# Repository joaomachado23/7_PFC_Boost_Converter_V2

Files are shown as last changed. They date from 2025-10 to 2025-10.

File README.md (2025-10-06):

# 7_PFC_Boost_Converter_V2

O objetivo deste trabalho foi o design, simulação, conceção e teste de um protótipo funcional de conversor de potência, a apresentar no final do semestre. Todos os grupos tiveram de desenvolver um Conversor CA-CC do tipo Boost PFC, respeitando requisitos de tensão e corrente definidos.

O conversor era constituído por um estágio CA-CC, com transformador abaixador e ponte retificadora de díodos (retificação síncrona), seguido de um estágio CC-CC na topologia Boost com carga resistiva. O estágio Boost operava com um método de controlo do tipo PFC (Power Factor Correction), cujo objetivo é corrigir o fator de potência e reduzir a potência reativa no sistema.

O nosso grupo optou por implementar um protótipo praticamente integrado em PCB, que inclui:

1. Andar de potência (com PGND) — engloba todos os componentes dos estágios CA-CC e CC-CC, incluindo sensores de tensão e de corrente (ambos de efeito Hall), excetuando o transformador, que ficou fora da PCB;

2. Andar de controlo (com SGND) — inclui:

  - Circuitos de alimentação auxiliares: num conector liga-se uma fonte de bancada que fornece ±15 V; essa tensão é depois convertida para 5 V e 3,3 V por reguladores (um conversor buck síncrono e um LDO).
  - Circuito de condicionamento de sinal: um IC com dois amplificadores operacionais em configuração diferencial (sensor de corrente) e em seguidor de tensão (sensor de tensão), filtros analógicos passa-baixo de primeira ordem e proteção para o ADC.
  - Microcontrolador e interface de comunicação série (UART ↔ USB): um STM32G474RET6 incorporado na placa, com os circuitos de alimentação, reset e programação dimensionados conforme a aplicação e o fabricante.

Todo o design foi concebido e verificado em ambiente de simulação (PSIM), tanto ao nível do hardware de potência como da teoria de controlo aplicada. Importa destacar que, nesta iteração, o controlo era linear: o sinal da gate do IGBT apresentava frequência fixa e era gerado por comparação entre uma portadora triangular (frequência e amplitude fixas) e uma moduladora, que corresponde à saída de um controlador PI. Essa moduladora era limitada posteriormente entre 0 e 70 (i.e., duty-cycle fisicamente limitado entre 0% e 70%).

O conversor era controlado por corrente, com referência de corrente do lado da rede (4 Arms). A referência era comparada com o valor instantâneo da corrente na bobina; a diferença constituía a entrada do controlador PI.

Os resultados obtidos foram bastante satisfatórios e promissores, sobretudo tendo em conta que a tecnologia ficou praticamente toda embebida na PCB, incluindo o microcontrolador. Para tornar o conversor independente de fontes de bancada externas, o grupo considerou ser adequado, numa versão futura, ligar um módulo conversor CC-CC isolado à saída da ponte retificadora, tomando os cuidados necessários para não comprometer o objetivo do controlo PFC.

Conteúdos disponíveis neste repositório:

- PDF com toda a documentação do projeto (apresentação): estado da arte, design, simulação, conceção, testes e resultados.

- Ficheiro rar com fotos e vídeos do protótipo.

- Pasta com prints de resultados dos testes ao conversor.

- Ficheiro PSIM (.psimsch) com a simulação do conversor.
  
- Pasta com o projeto da PCB feito em Altium.

Este trabalho foi fundamental para explorar o desafio de integrar toda a tecnologia numa PCB e para consolidar conhecimentos em eletrónica de potência, com foco no hardware de potência, condicionamento de sinal e firmware de controlo. Foi um projeto exigente, dadas todas as condicionantes a ter em atenção e não esquecendo a função principal do conversor, mas foi concluído com sucesso.

Um grande obrigado aos colegas que me acompanharam nesta jornada: Diego Brandão, Francisco Costa, João Santos e Rui Pedroso.

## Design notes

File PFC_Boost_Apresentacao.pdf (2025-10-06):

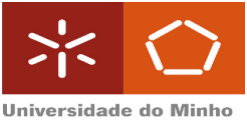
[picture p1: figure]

Escola de Engenharia
Departamento de Electrónica Industrial

## Eletrónica de Potência e Energias

## Conversor Unidirecional CA-CC Boost PFC

Dep. de Electrónica Industrial

## Constituição do grupo

◼ Diego Soares Brandão

◼ pg53769@alunos.uminho.pt

◼ Francisco Faria Costa

◼ pg53819@alunos.uminho.pt

◼ João Pedro Machado da Silva

◼ pg53942@alunos.uminho.pt

◼ João Pedro Medeiros Santos

◼ a94596@alunos.uminho.pt

◼ Rui Pedro Fernandes Pedroso

◼ | pg54212@alunos.uminho.pt
06/10/2025 | Universidade do Minho, MEEIC - EPE | 2

Dep. de Electrónica Industrial

## Índice

◼ Estado da arte;

◼ Diagrama de blocos;

◼ Etapas do trabalho desenvolvido;

◼ Simulação;

◼ Hardware;

◼ Testes e Resultados experimentais;
◼ Conclusão;

◼ Bibliografia;

Dep. de Electrónica Industrial

## Estado da Arte

◼ O algoritmo Power Factor Correction (Correção do Fator de Potência – PFC) surge como uma ferramenta para otimizar a utilização da energia;

◼ É cada vez mais necessário reduzir as perdas, devido ao aumento do consumo de energia;

◼ A otimização da energia é feita não só através da correção do fator de potência, mas também através do consumo de corrente sinusoidal;

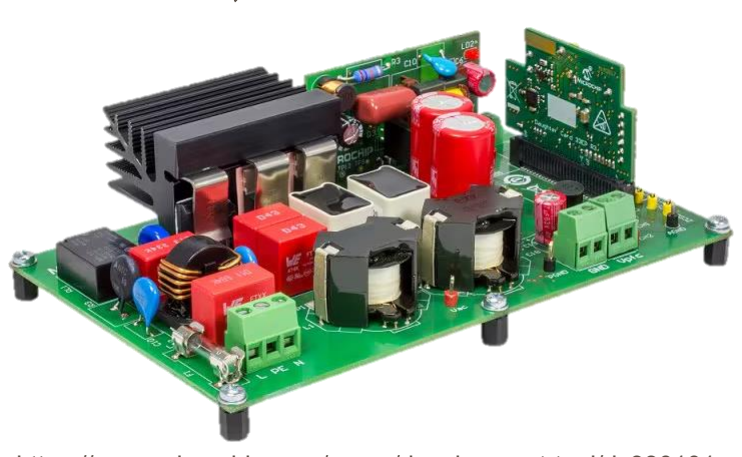
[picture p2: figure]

https://www.microchip.com/en-us/development-tool/dv330101

## Diagrama de blocos

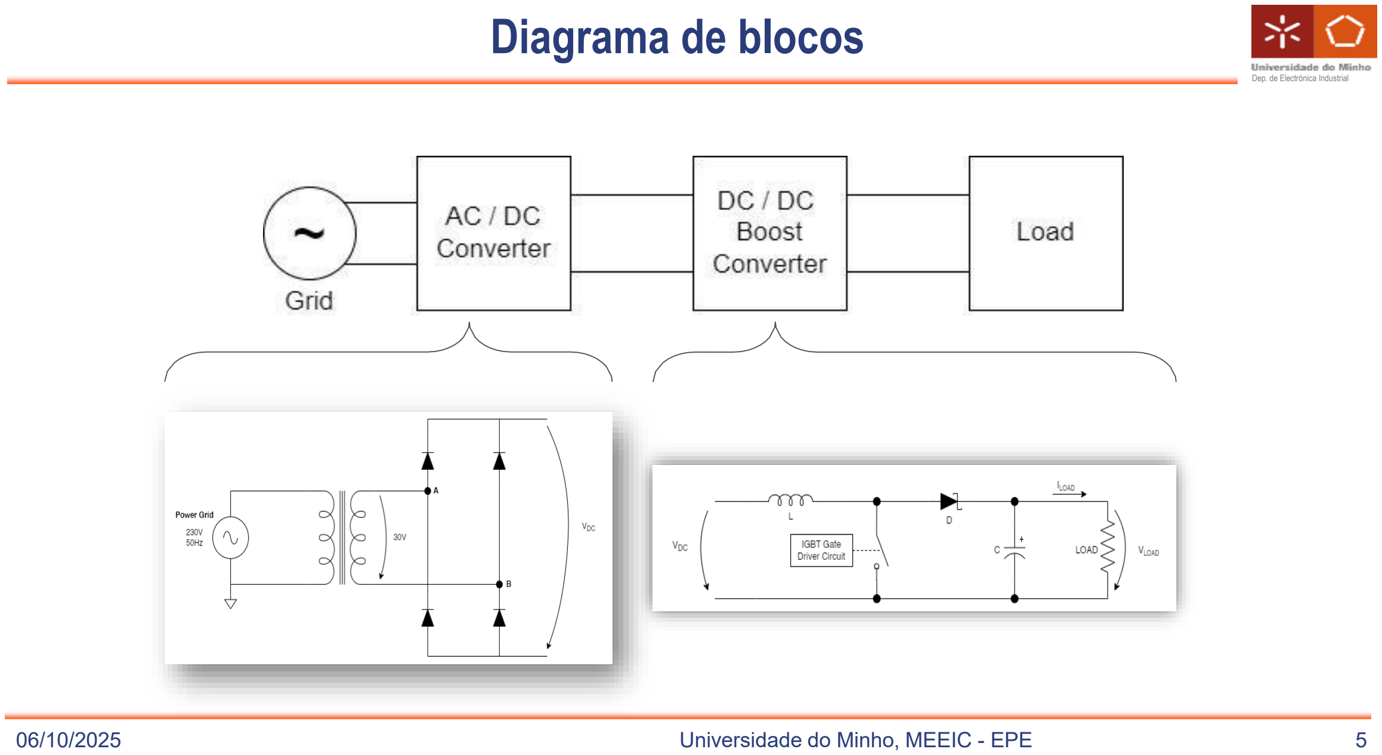
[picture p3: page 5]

Dep. de Electrónica Industrial

## Circuito simulado com valores reais

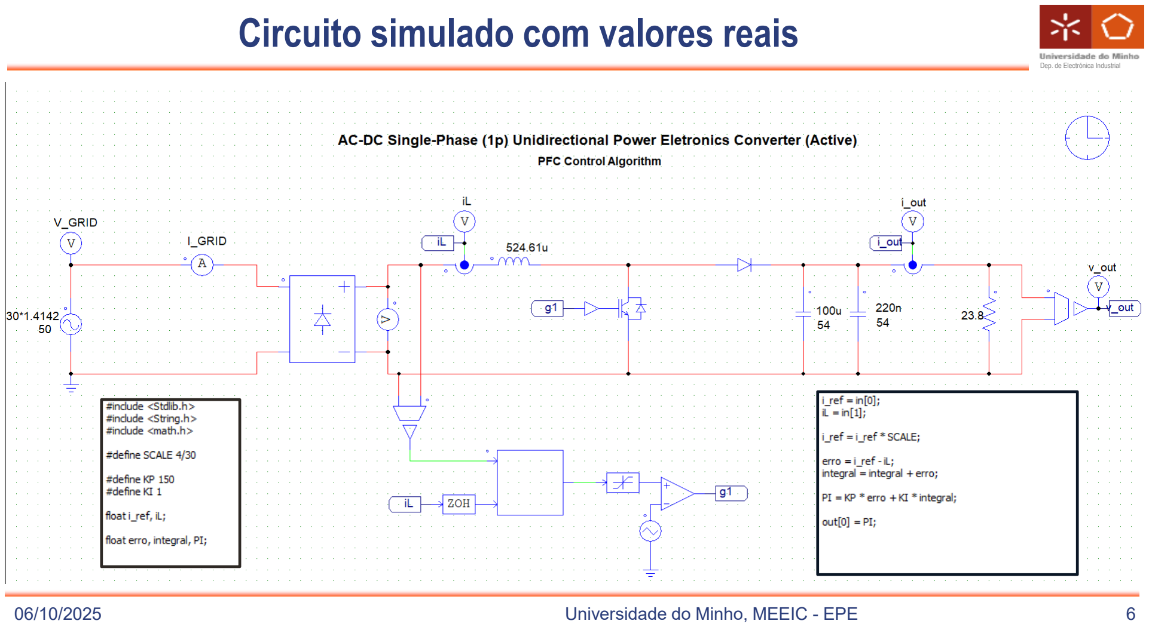
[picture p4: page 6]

Dep. de Electrónica Industrial

## Resultados da simulação: (trocar a print)

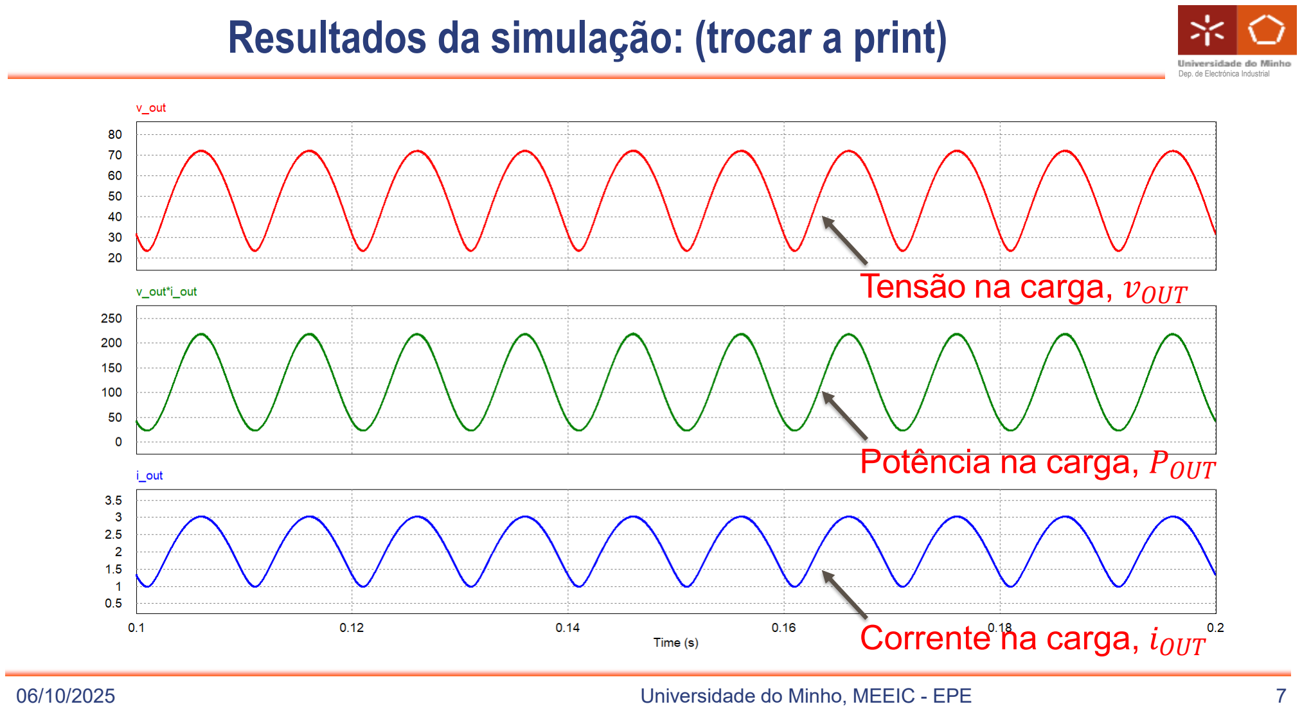
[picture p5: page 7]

Dep. de Electrónica Industrial

Tensão na carga, vOUT

Potência na carga, POUT

Corrente na carga, iOUT

## Resultados da simulação (trocar as prints)

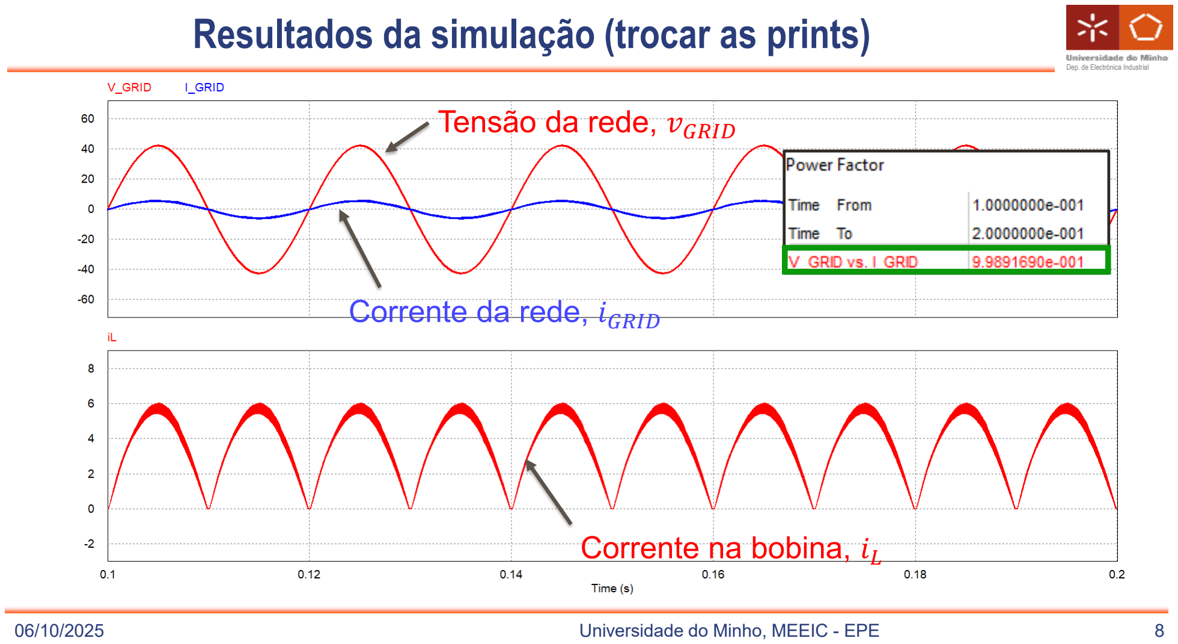
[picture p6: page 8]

Dep. de Electrónica Industrial
Tensão da rede, vGRID

Corrente da rede, iGRID

Corrente na bobina, iL

Dep. de Electrónica Industrial

## Controlo

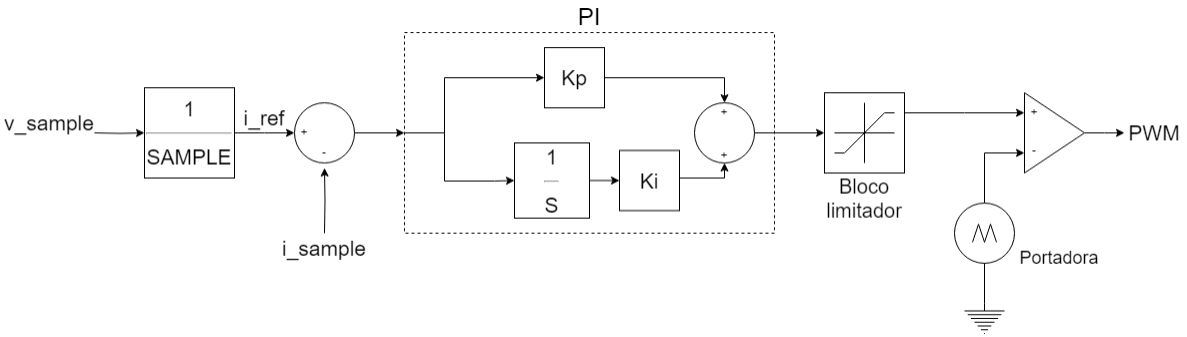
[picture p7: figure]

06/10/2025 | Universidade do Minho, MEEIC - QEFAP | 9

◼ Teoria de controlo utilizada – PI estacionário com modulação PWM (controlo linear)

Dep. de Electrónica Industrial

## Hardware

◼ Microcontrolador utilizado: SMT32G474RET6

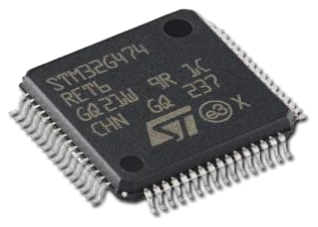
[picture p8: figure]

◼ Clock até 170MHz;

◼ 5 x ADCs de 12Bits, 4MSps;

◼ 17 timers, 6 deles de 16Bit;

◼ Mathematical Hardware Acelerator;

◼ FPU;

06/10/2025 | Universidade do Minho, MEEIC - QEFAP | 10

https://pt.aliexpress.com/i/1005005631876638.html

Dep. de Electrónica Industrial

## Hardware

◼ Gate driver: ADuM 3123

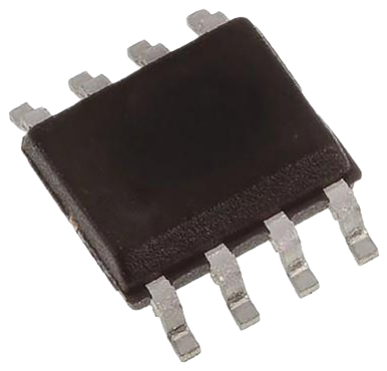
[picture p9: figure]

◼ Bandwitdh de 1MHz;

◼ 3000V rms isolation;

◼ 64ns maximum propagation delay;

06/10/2025 | Universidade do Minho, MEEIC - QEFAP | 11

https://sg.rs-online.com/web/p/digital-isolator-ics/9053567

Dep. de Electrónica Industrial

## Hardware

◼ Sensor de tensão: CYHVS5-25A

◼ Tensão máxima de entrada: 2000V;

◼ Tensão de isolamento 2.5kV;

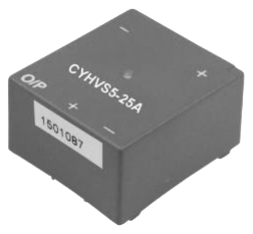
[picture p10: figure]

06/10/2025 | Universidade do Minho, MEEIC - QEFAP | 12

◼ Sensor de tensão: LTSR15-np

◼ Corrente máxima de entrada: 15A;

◼ Sensibilidade: 41.6mV/A;

https://shorturl.at/5qOIk

## Hardware - PCB

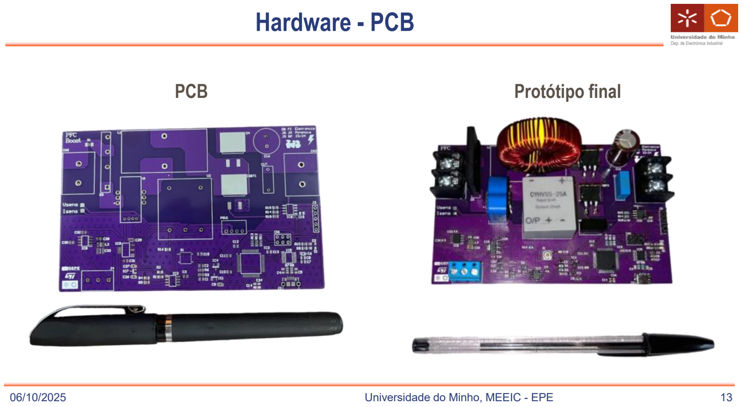
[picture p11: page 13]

Dep. de Electrónica Industrial

PCB

Protótipo final

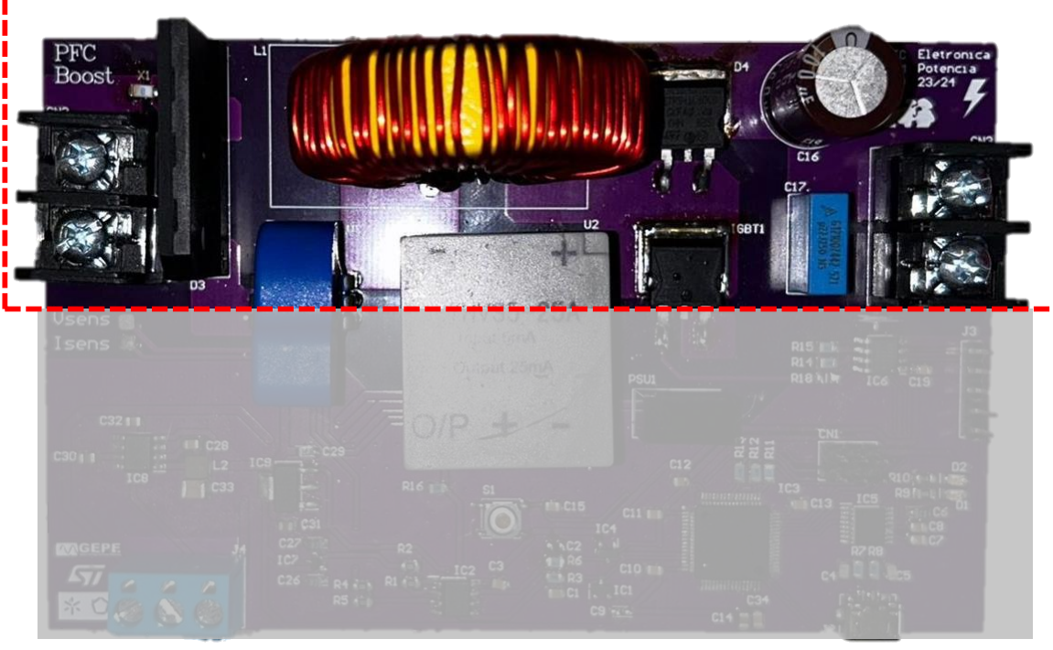
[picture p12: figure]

Dep. de Electrónica Industrial

## Hardware - PCB

Circuito de
potência

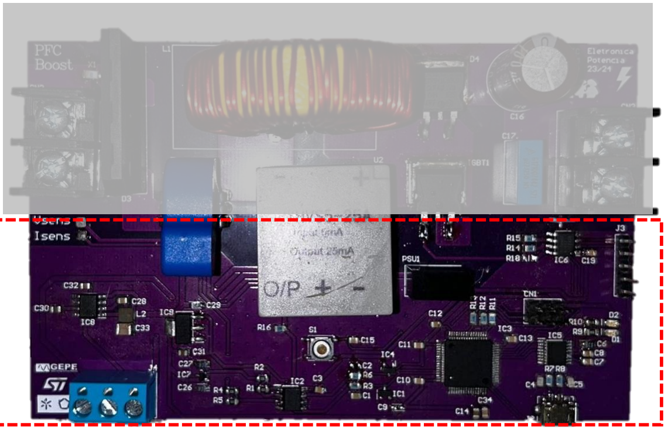
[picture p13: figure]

Dep. de Electrónica Industrial

## Hardware - PCB

Circuito de
controlo

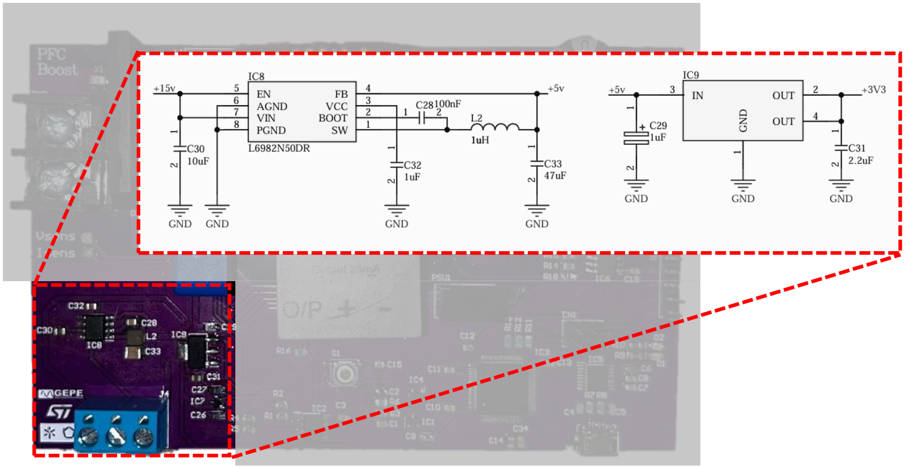
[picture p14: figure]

Dep. de Electrónica Industrial

## Hardware - PCB

Circuito de
alimentações

## Hardware - PCB

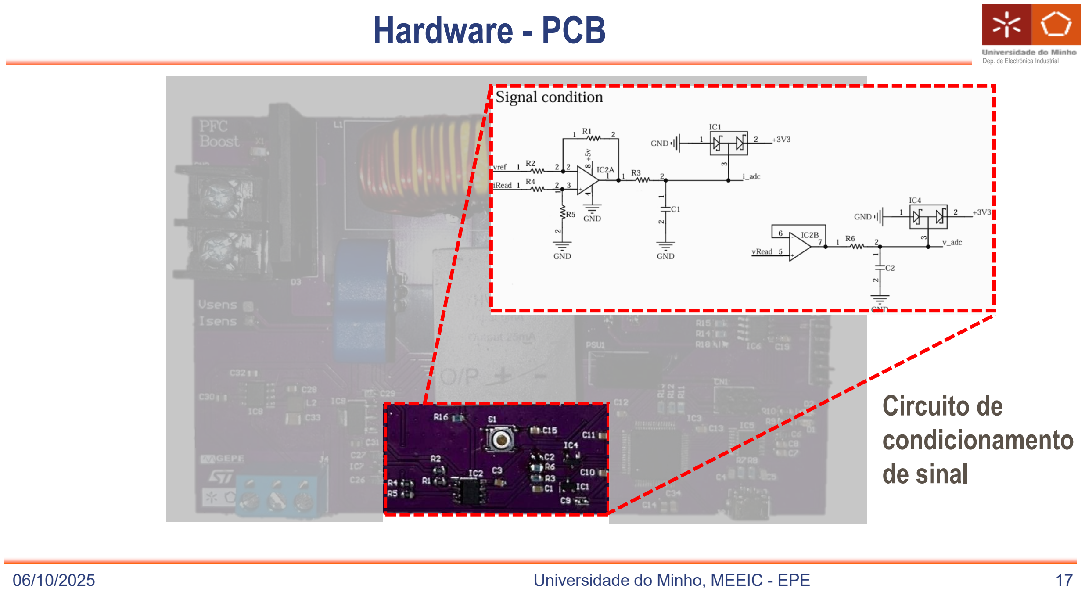
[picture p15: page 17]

Dep. de Electrónica Industrial

Circuito de
condicionamento
de sinal

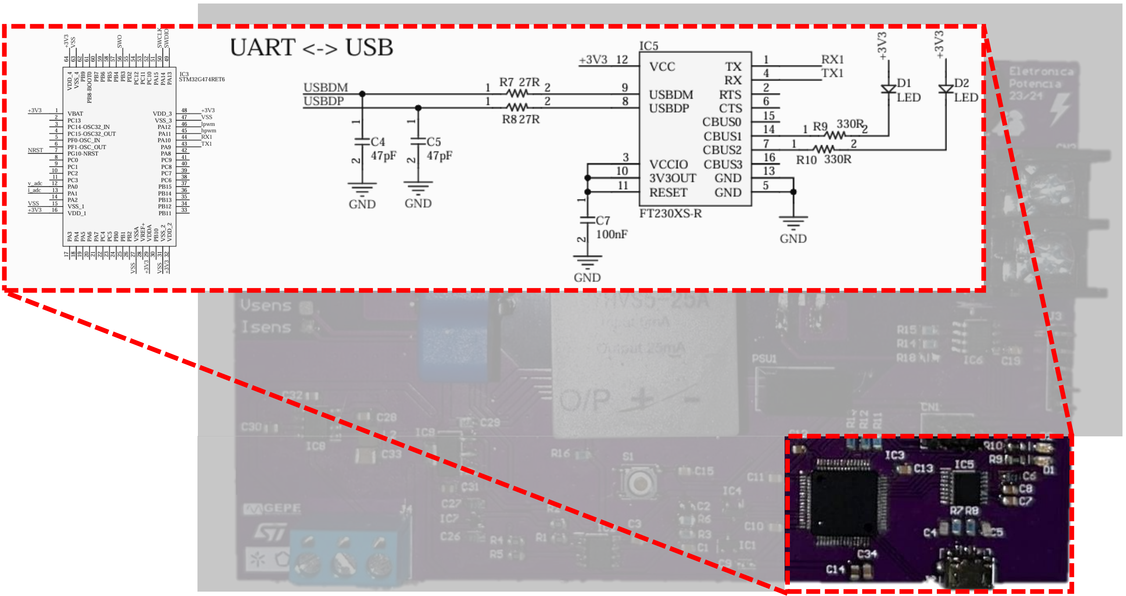
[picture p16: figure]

Dep. de Electrónica Industrial

## Hardware - PCB

Microcontrolador
e circuito para
comunicação por
porta série

## Bancada de testes

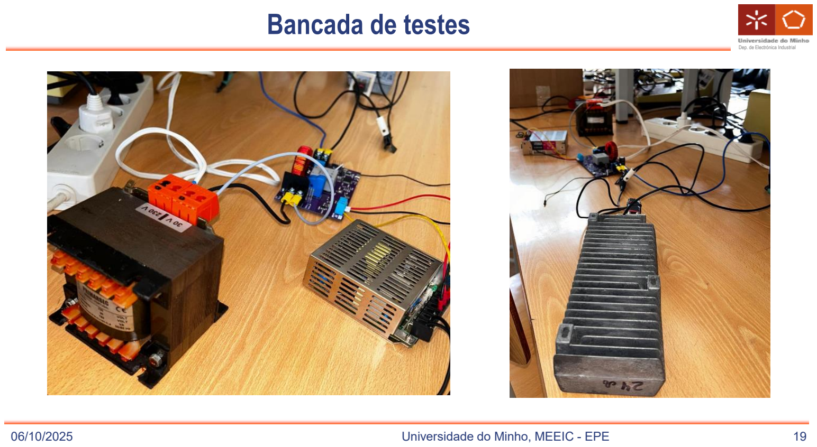
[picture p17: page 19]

Dep. de Electrónica Industrial

Dep. de Electrónica Industrial

## Resultados experimentais - Testes pwm

PWM do circuito de controlo

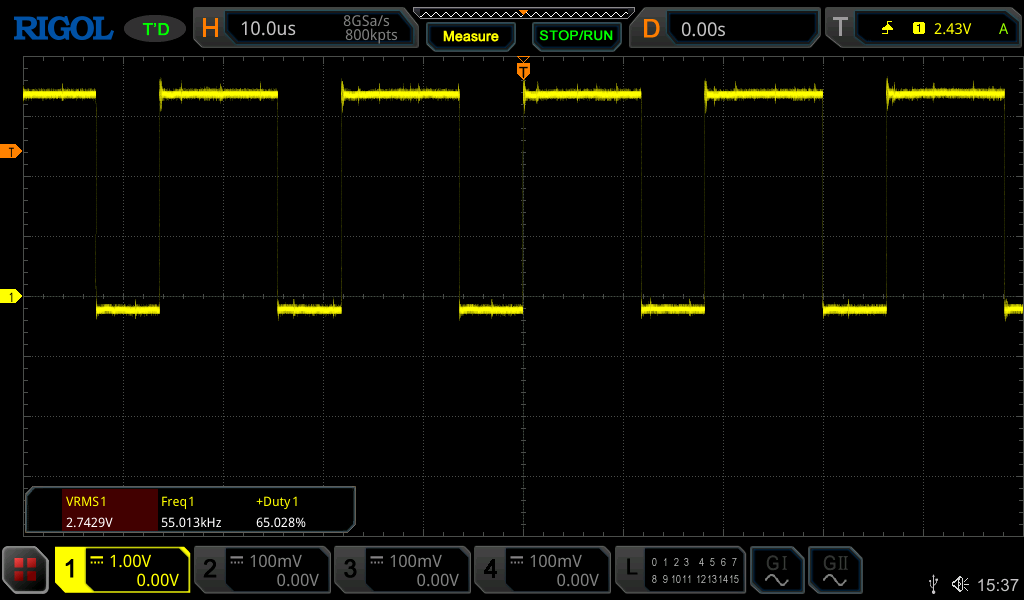
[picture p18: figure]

Duty = 65%

Dep. de Electrónica Industrial

## Resultados experimentais – Testes pwm

PWM no circuito de potência

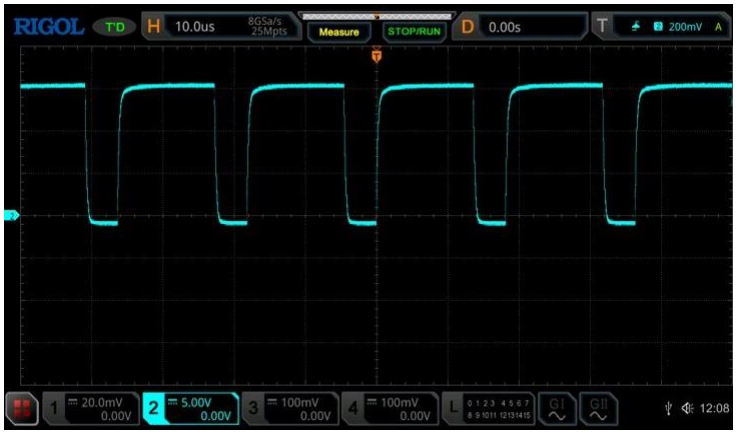
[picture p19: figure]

Duty = 75%

## Resultados experimentais - Modo Boost

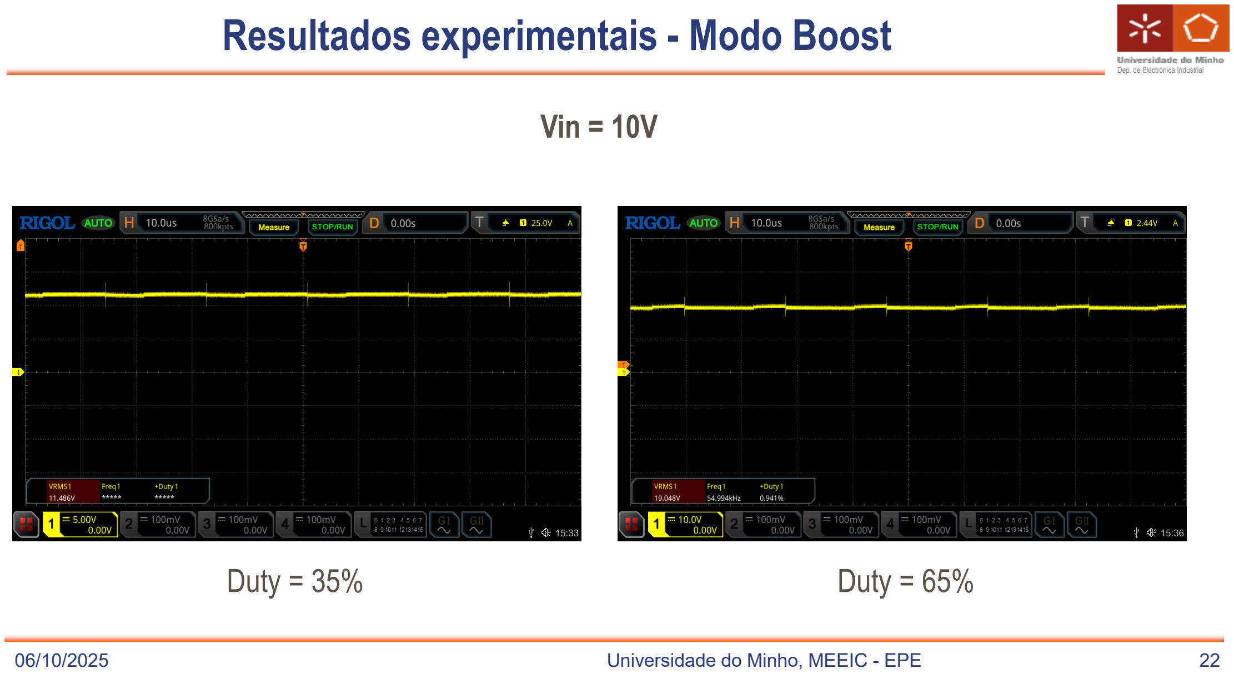
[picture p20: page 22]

Dep. de Electrónica Industrial

Duty = 35% | Duty = 65%

Vin = 10V

## Resultados experimentais - testes sem controlo

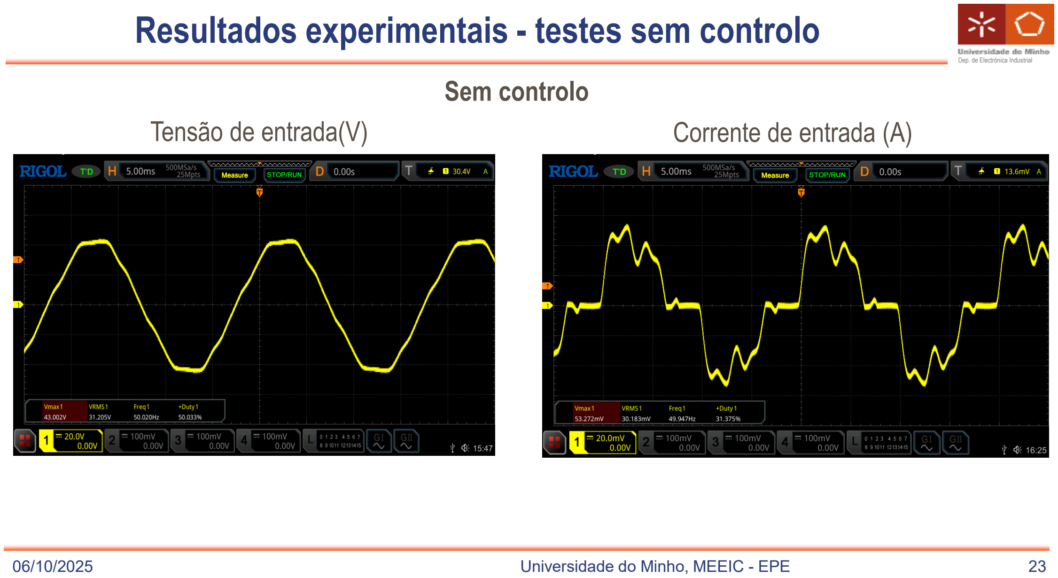
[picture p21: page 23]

Dep. de Electrónica Industrial
Sem controlo
Tensão de entrada(V) | Corrente de entrada (A)

## Resultados experimentais - testes sem controlo

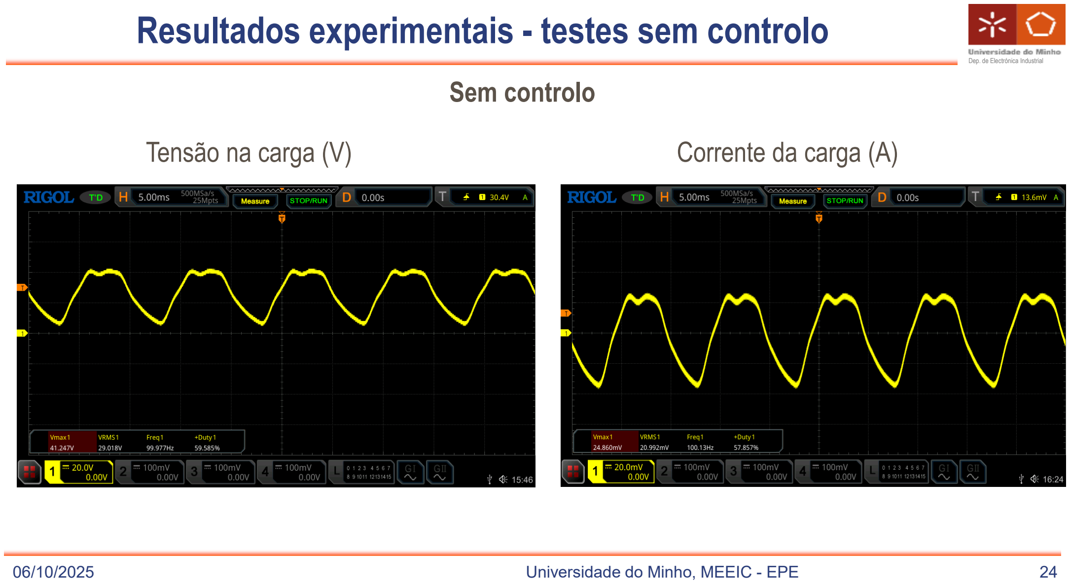
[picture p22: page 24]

Dep. de Electrónica Industrial
Sem controlo
Tensão na carga (V) | Corrente da carga (A)

Dep. de Electrónica Industrial

## Resultados experimentais - controlo PFC

Corrente e tensão de entrada

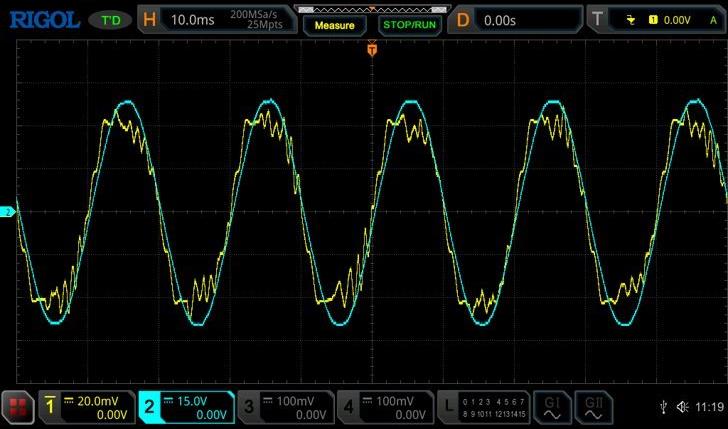
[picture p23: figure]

Corrente de
entrada: CH1

Tensão de
entrada: CH2

Dep. de Electrónica Industrial

## Conclusão

◼ Este conversor de potência com controlo por PFC evidencia-se como uma tecnologia inovadora e importante para a melhoria da eficiência e qualidade da energia elétrica.

◼ Melhora o fator de potência global dos sistemas, conduzindo a uma melhor qualidade de energia da rede.

◼ Molda ativamente a forma de onda da corrente de entrada, otimizando o fornecimento de energia e diminuindo a distorção harmónica total percentual (THD%).

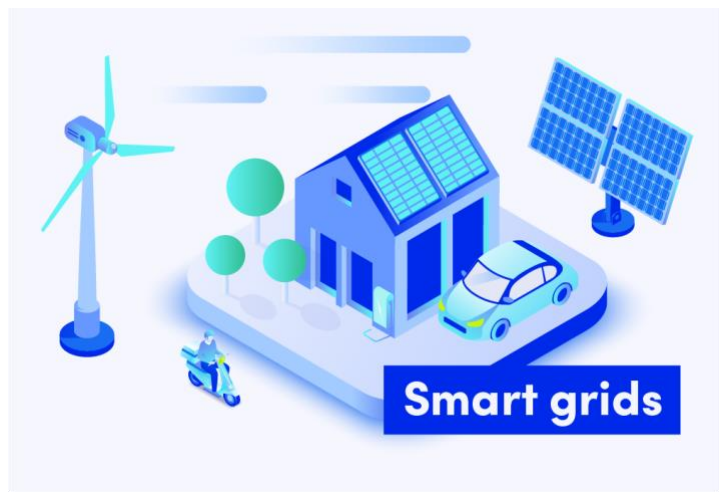
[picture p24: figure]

https://solidstudio.io/blog/smart-grids-what-are-they

Dep. de Electrónica Industrial

## Agradecimentos

## Obrigado pela atenção!

Dep. de Electrónica Industrial

## Bibliografia

◼ Vítor Monteiro, Andrés A. Nogueiras Meléndez, João L. Afonso, “Novel Single-Phase Five-Level VIENNA-Type Rectifier with Model Predictive Current Control”, IEEE IECON Industrial Electronics Conference, pp. 6413-6418, Beijing China, Oct. 2017. DOI: 10.1109/IECON.2017.8217117 ISBN: 978-1-5386-1127-2

◼ João L. Afonso, João L. , Monteiro, Vitor – Apresentações da Unidade Curricular de Eletrónica de Potência para Redes Elétricas Inteligentes, atualizado abril 2024

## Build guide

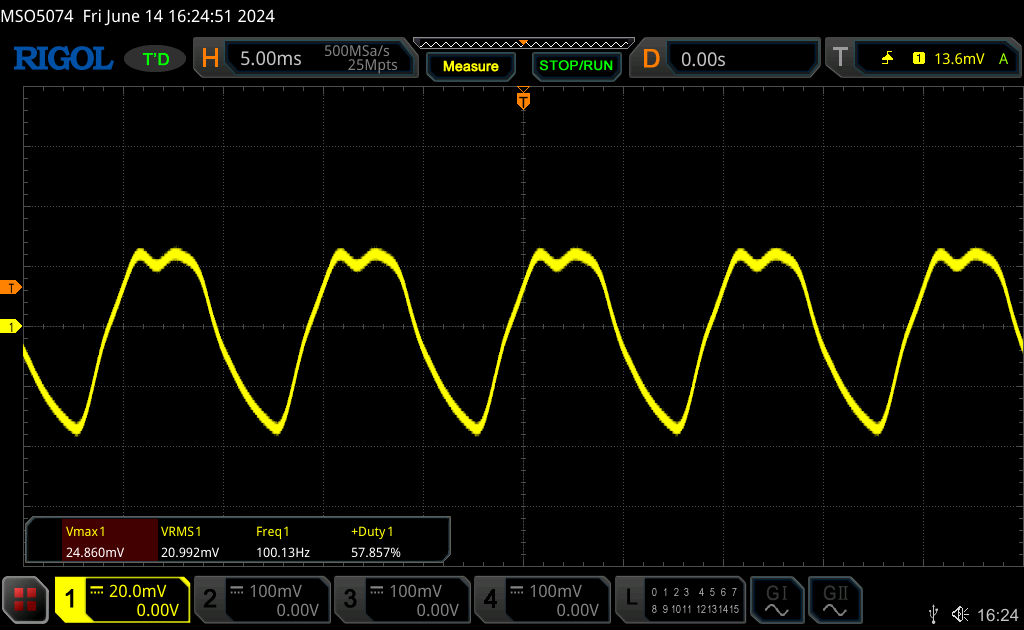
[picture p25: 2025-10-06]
Testes & Resultados -Prints/outCurrent_semCONT0.png

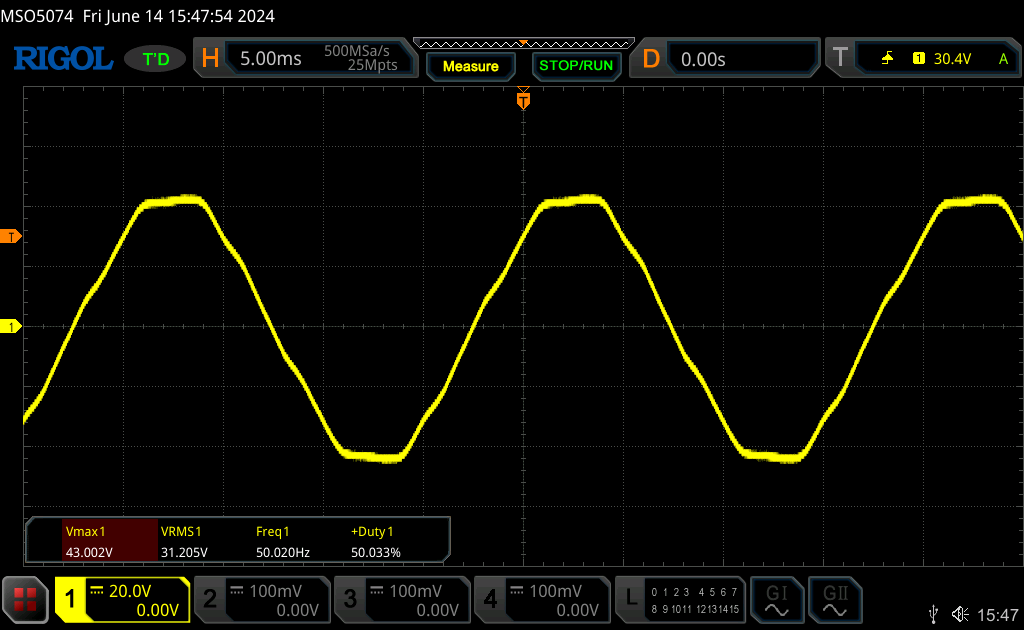
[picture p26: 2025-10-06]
Testes & Resultados -Prints/inputTransf_semControlo.png

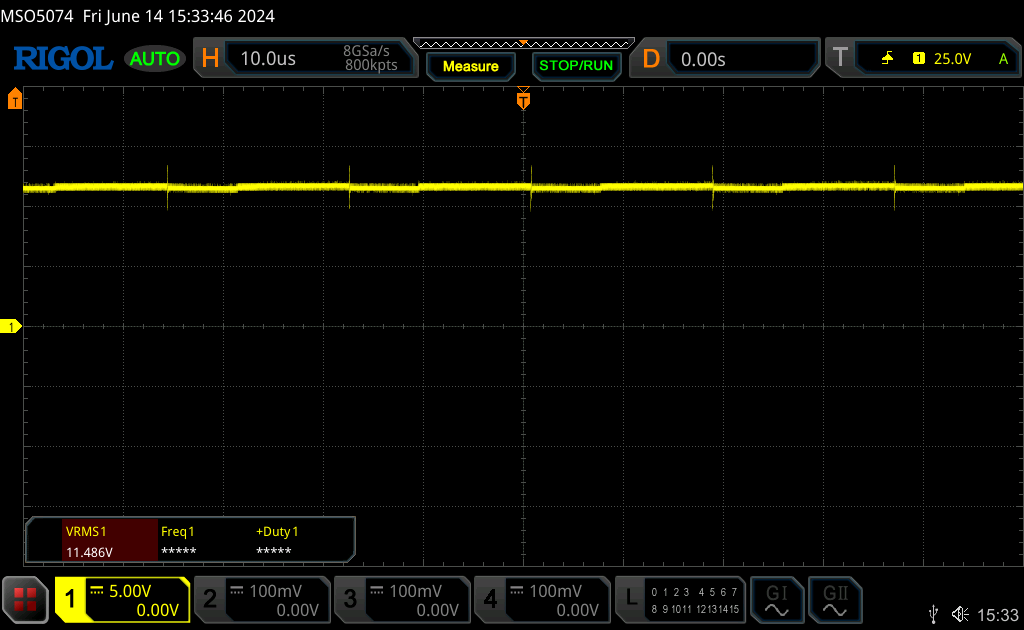
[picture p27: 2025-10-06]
Testes & Resultados -Prints/out10v0.35.png

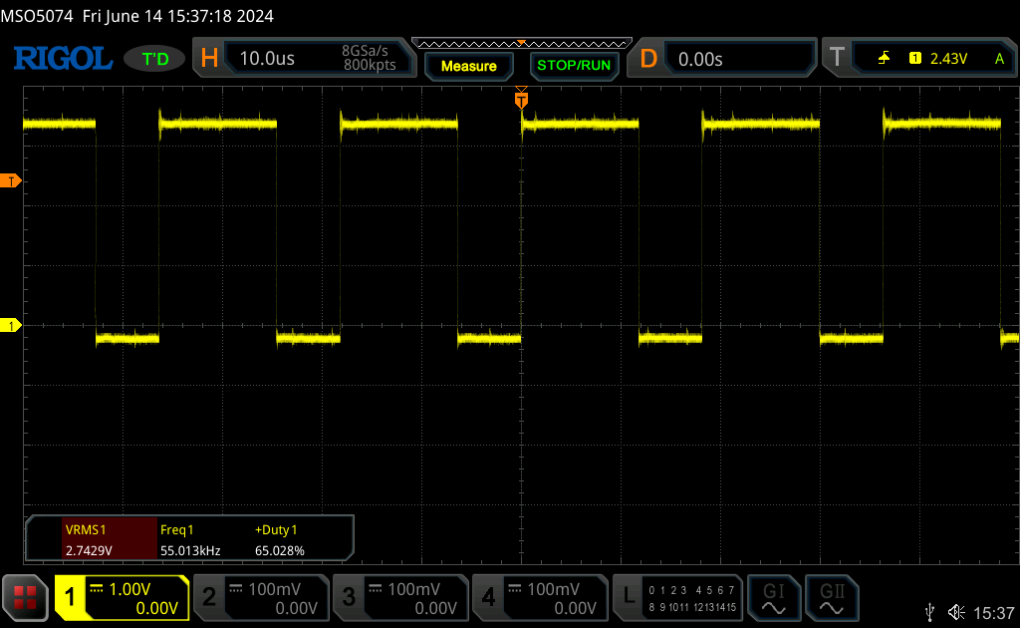
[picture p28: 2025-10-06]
Testes & Resultados -Prints/pwm0.65.png

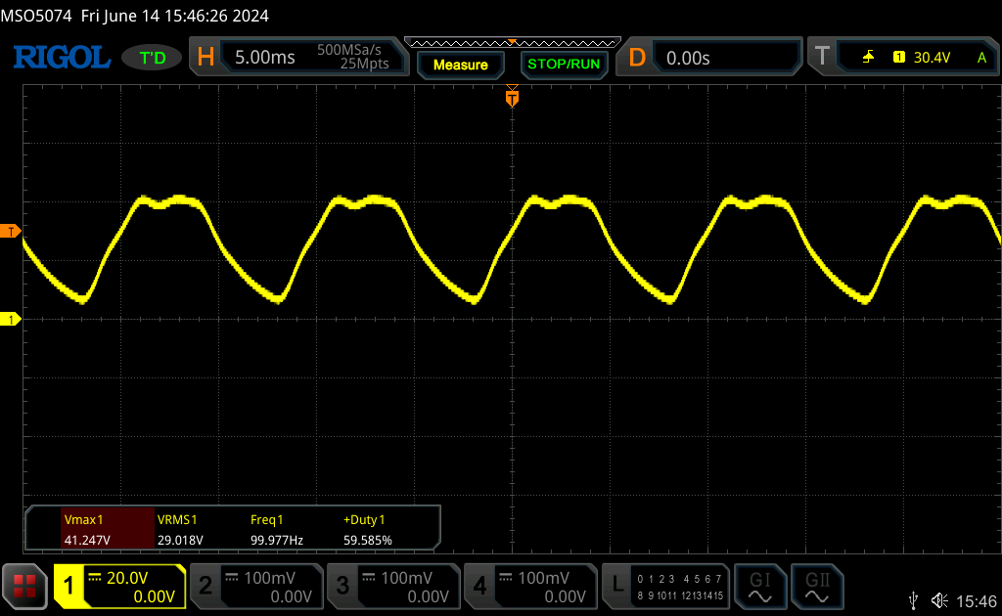
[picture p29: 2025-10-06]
Testes & Resultados -Prints/outTransf_semControlo.png

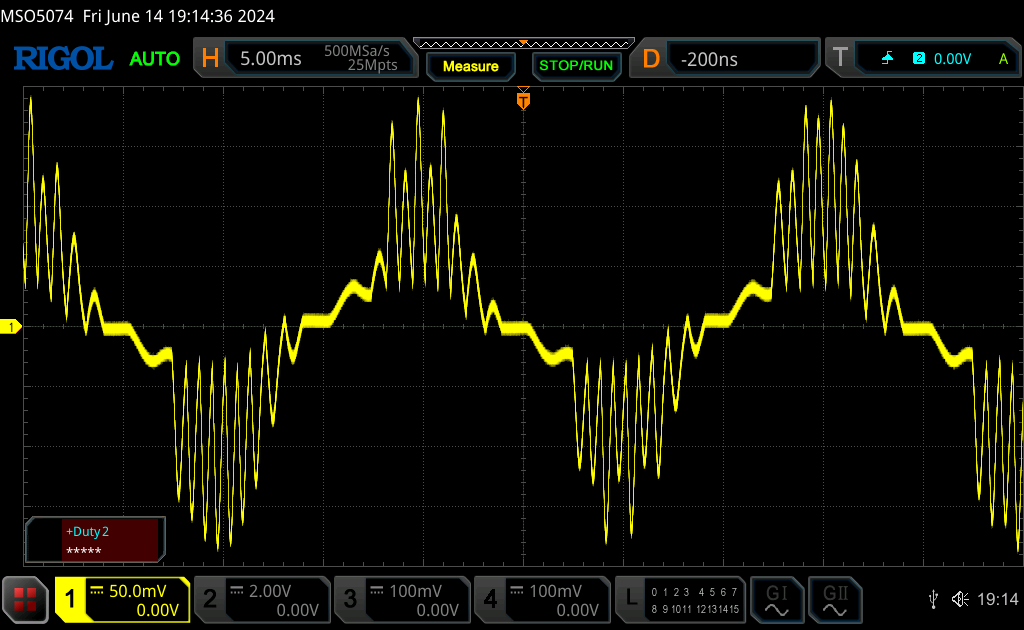
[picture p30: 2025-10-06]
Testes & Resultados -Prints/RigolDS0.png
